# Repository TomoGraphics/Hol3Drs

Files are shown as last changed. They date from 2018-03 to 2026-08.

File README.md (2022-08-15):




# OpenSCAD models

This repository is a collection of sample holder for our [uCT scanners](http://bruker-microct.com/products/all_products.htm) (Bruker SykScan 1172, 1272 and 2214).

Models are generated/written in [OpenSCAD](http://www.openscad.org/).
The .scad-Files in this folder are the *originals*.
Those are then exported to [STL](https://en.wikipedia.org/wiki/STL_(file_format)) files (into the [STL](STL) folder) to be printed on our [Form 2](http://formlabs.com/products/3d-printers/form-2/) 3D printer.
This also makes it possible to nicely view the STL files, since [GitHub renders them in 3D](https://github.com/blog/1465-stl-file-viewing).

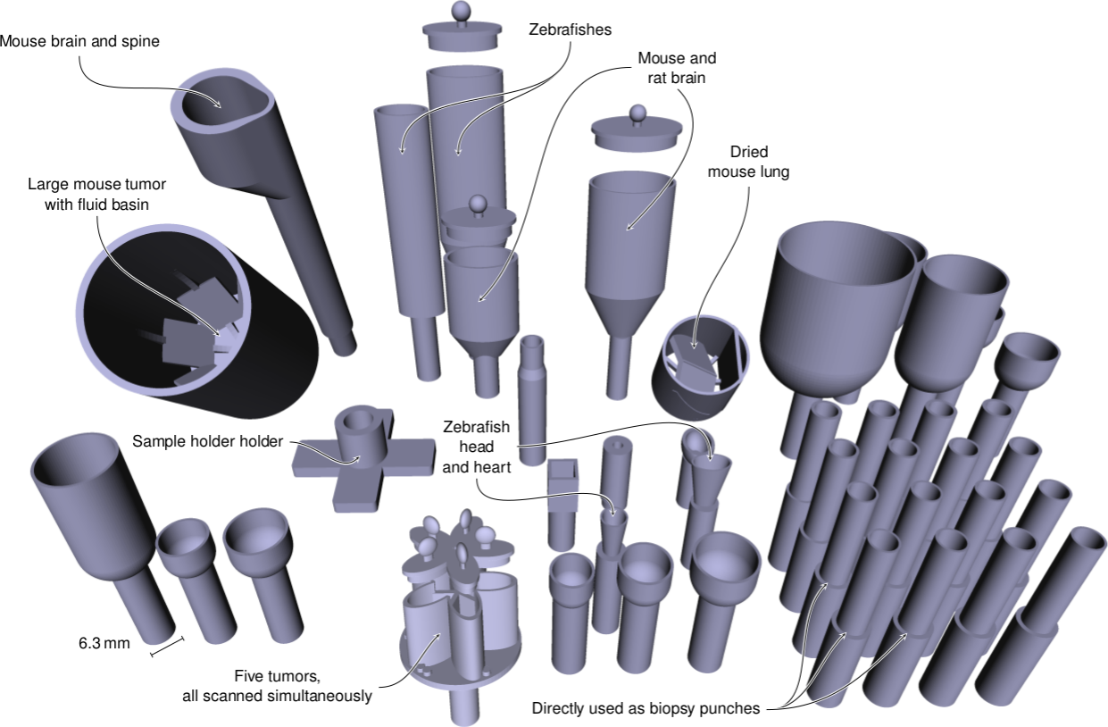
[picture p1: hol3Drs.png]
A sampler of our 3D printed sample holders


# [Contributions welcome](http://contributionswelcome.org/)

All contributions (no matter how small) are always welcome.
To see how you can help and where to start [see the Contributing file](CONTRIBUTING.md).

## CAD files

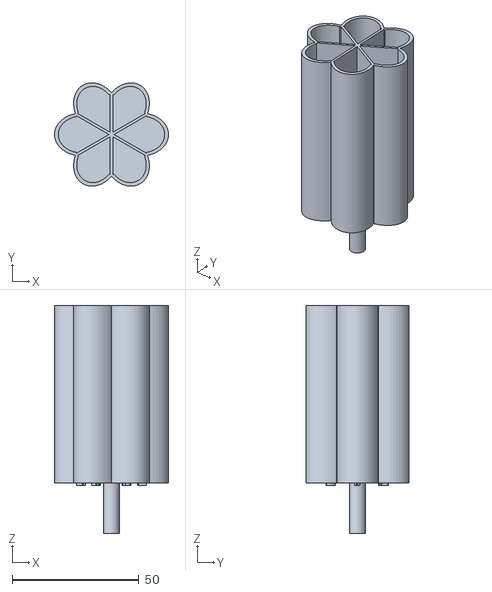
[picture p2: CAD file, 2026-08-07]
STL/Stickleback.Multiple.stl
45.0 x 40.8 x 90.0

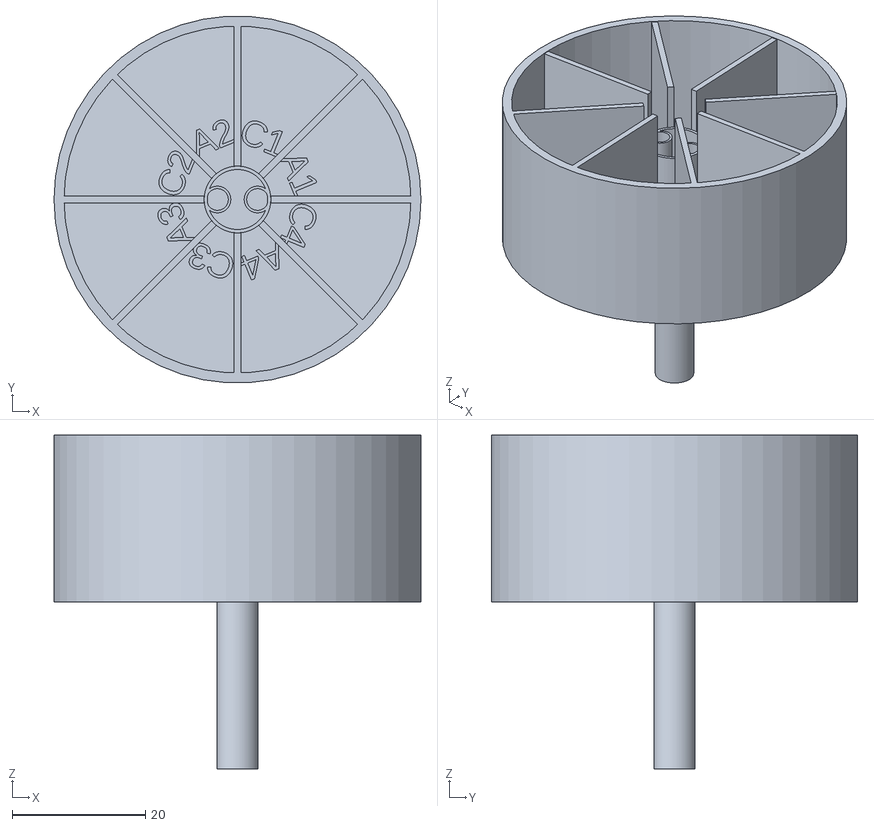
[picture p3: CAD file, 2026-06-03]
STL/BoneChunks.stl
55.0 x 54.9 x 50.0

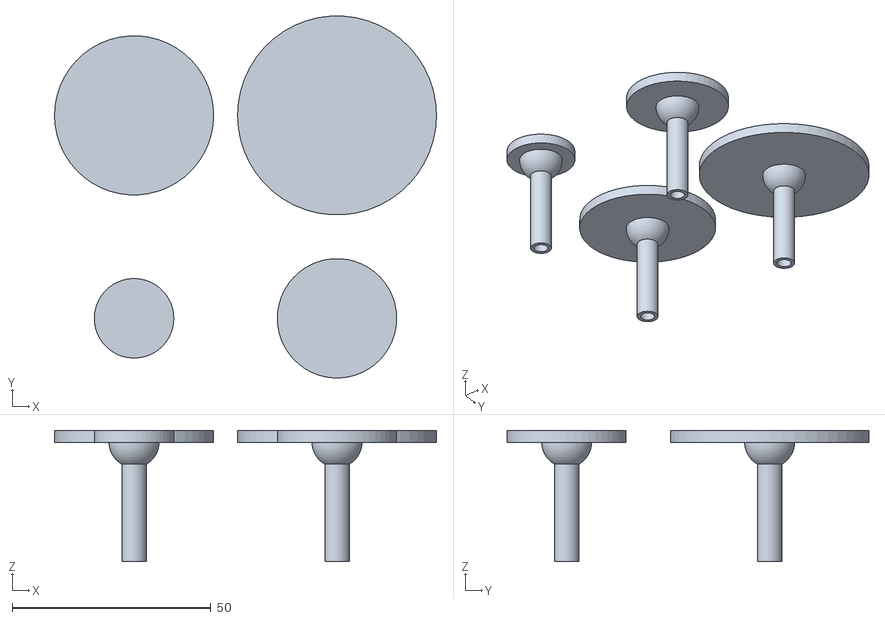
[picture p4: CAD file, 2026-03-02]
STL/SimplePlate.stl
96.0 x 90.9 x 33.0

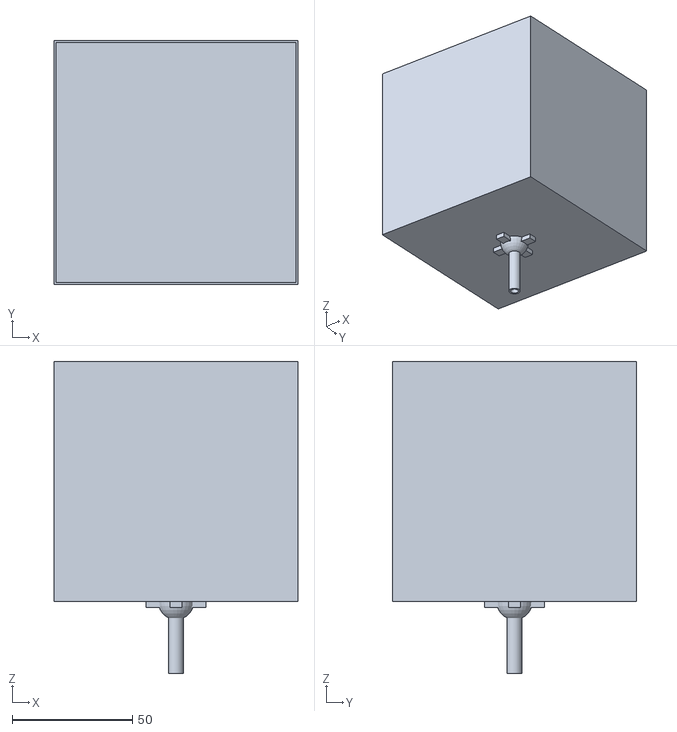
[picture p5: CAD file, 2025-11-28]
STL/Box.stl
101.5 x 101.5 x 130.0

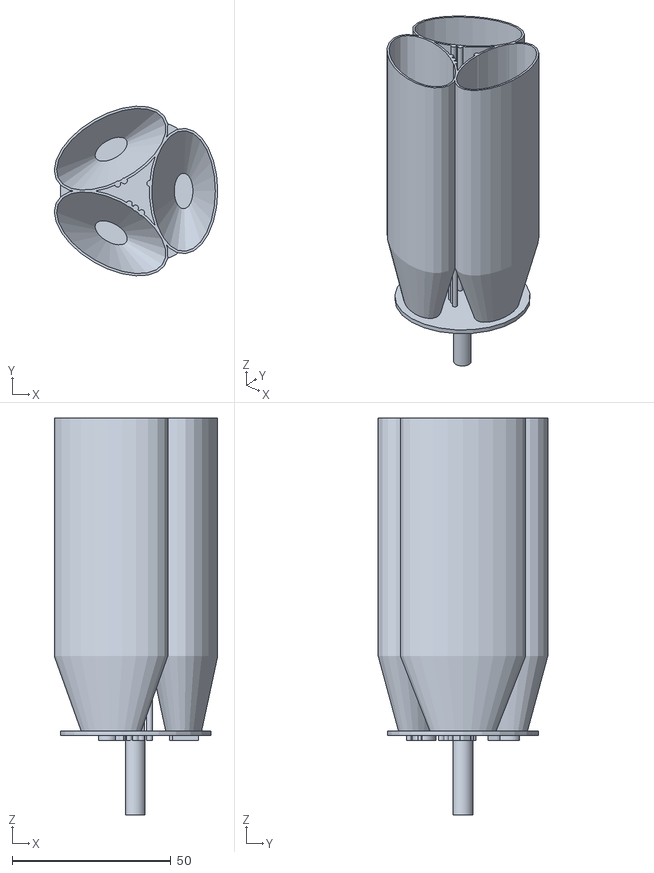
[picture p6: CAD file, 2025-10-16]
STL/EAWAG.Fish.Multiple.stl
51.5 x 53.4 x 125.0

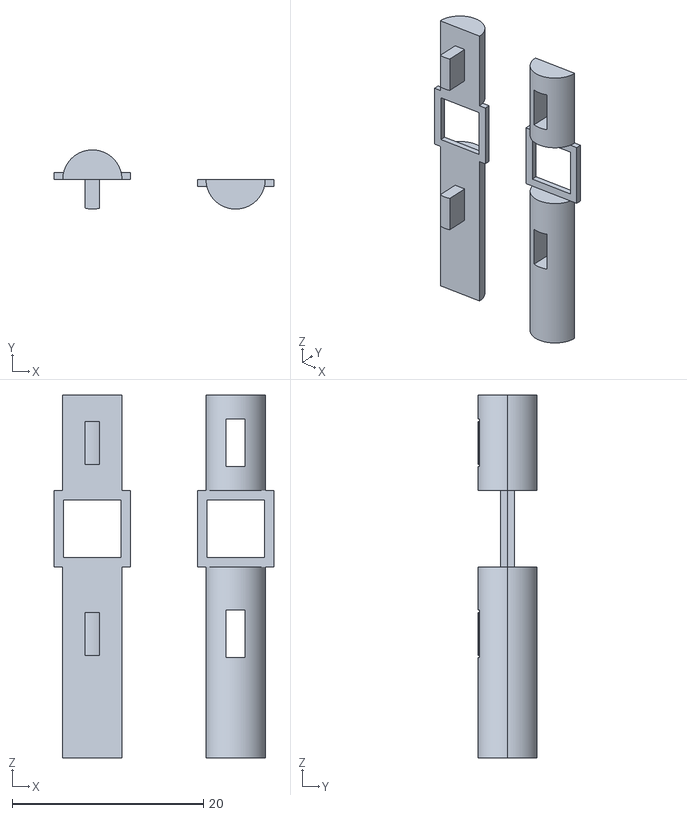
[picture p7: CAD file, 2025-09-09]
STL/FoamFrame.stl
23.0 x 6.20 x 38.0

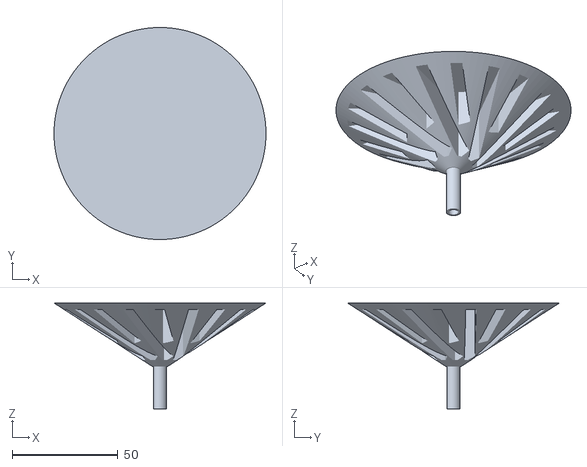
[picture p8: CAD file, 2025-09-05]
STL/BrukerHolderInPlastic.stl
100.0 x 100.0 x 50.0

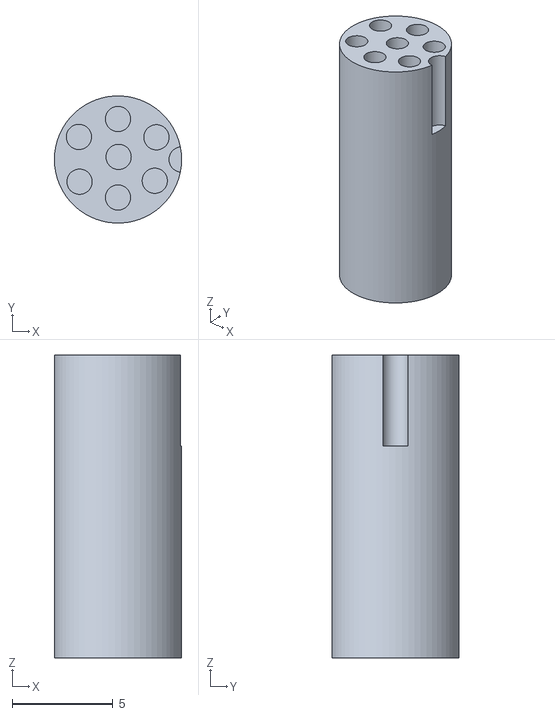
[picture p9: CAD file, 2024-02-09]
STL/DrillHolder.stl
6.30 x 6.29 x 15.0

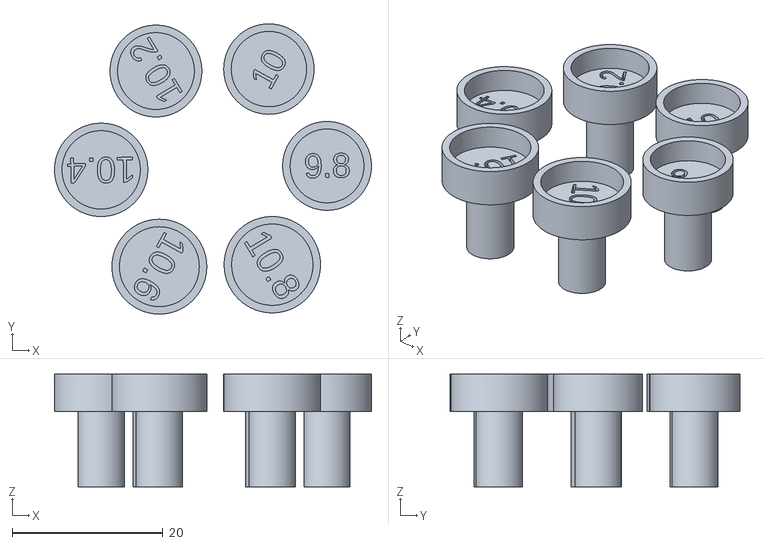
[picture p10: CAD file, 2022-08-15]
STL/Mouse.Lung.CriticallyPointDried.Kapton.stl
42.1 x 38.5 x 15.0

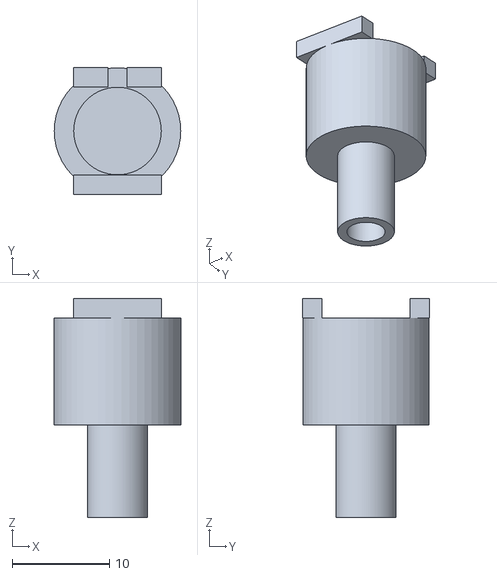
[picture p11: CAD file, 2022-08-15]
STL/Rabbit.Bone.Dome.stl
13.0 x 13.0 x 22.5

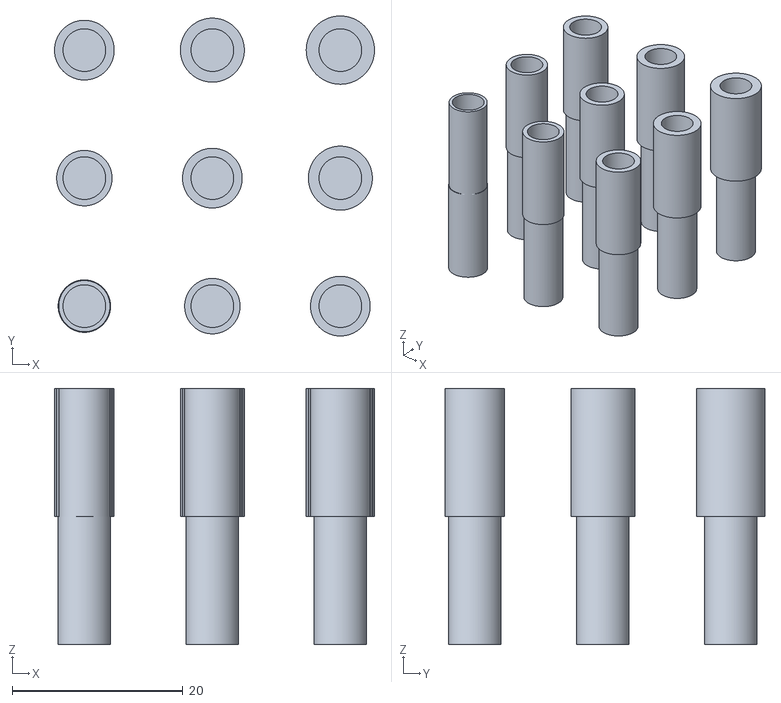
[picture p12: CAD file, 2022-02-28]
STL/Fossil.Shells.stl
37.5 x 37.5 x 30.0

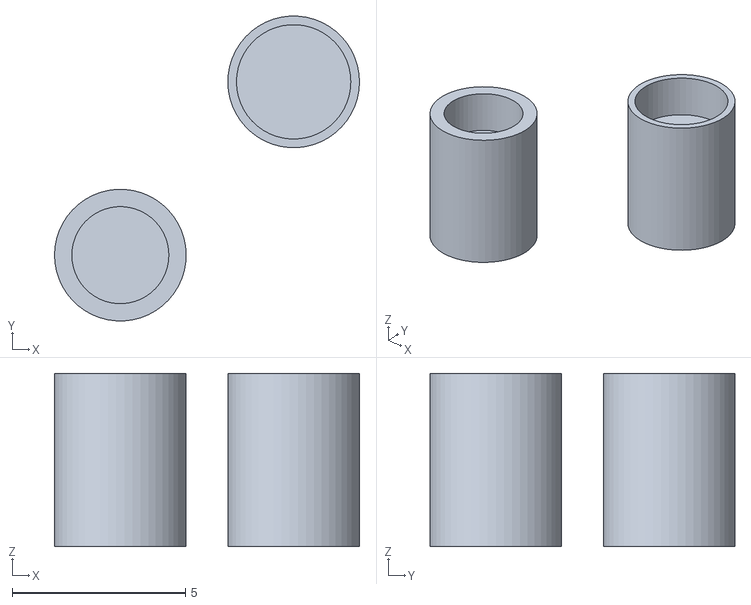
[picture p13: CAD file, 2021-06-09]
STL/Gastropod.Shell.Samplechanger.stl
8.80 x 8.79 x 5.00

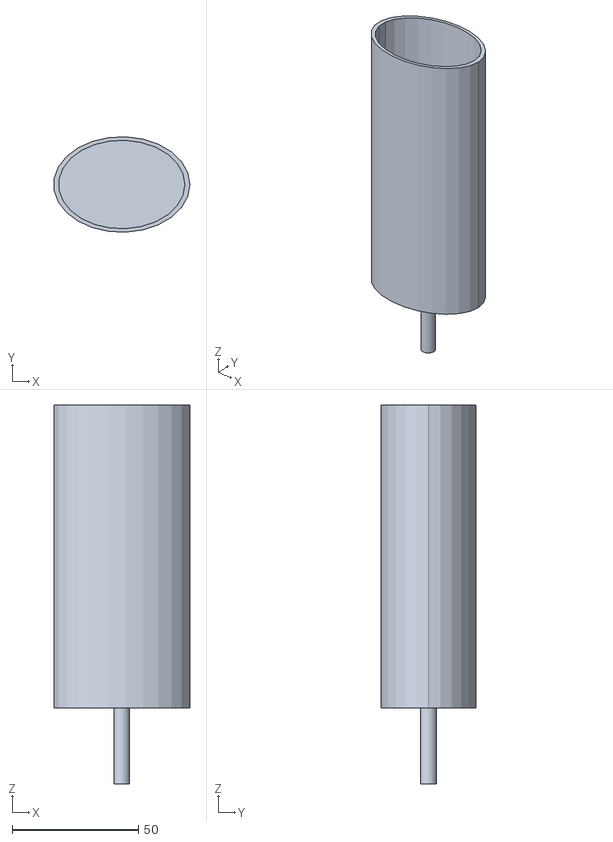
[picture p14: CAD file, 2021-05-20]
STL/EAWAG.Fish.stl
53.8 x 37.7 x 150.0

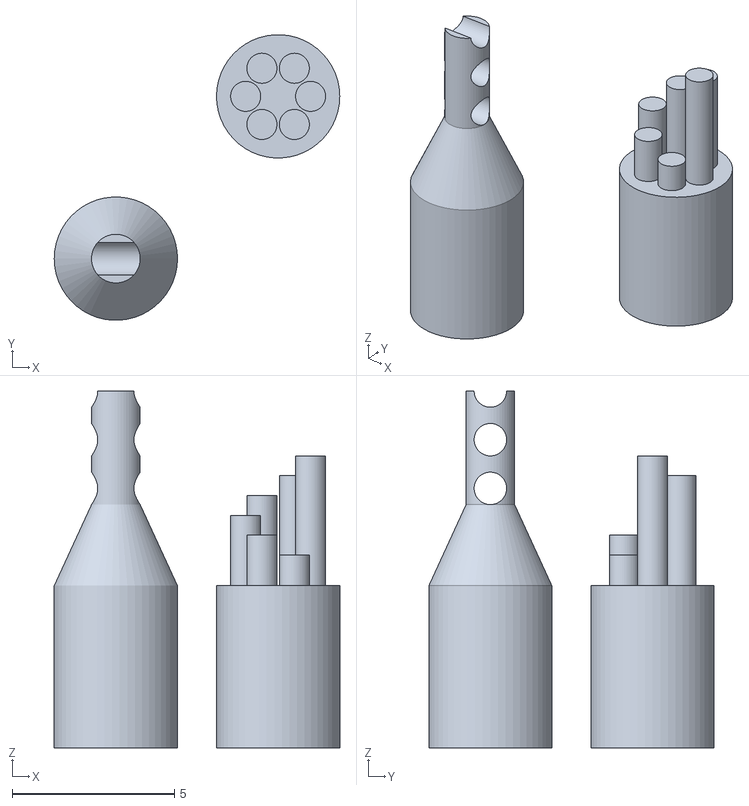
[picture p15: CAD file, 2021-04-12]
STL/Chondrules.stl
8.80 x 8.79 x 11.0

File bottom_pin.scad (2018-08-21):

// This is the bottom pin which is used to mount the sample holders into the machines.
// Since we use this for most of our models, it makes sense to have a small 'template' which we can just add the model where it's needed...
// To do so, add a line with "use<bottom_pin.scad>"
// And then just call "pin();" wherever you need the pin :)
$fn=100;
module pin(diameter=6.15, height=20, cap_depth=2)
{
    translate([0,0,-height]) difference(){
        cylinder(d=diameter,h=height);
        cylinder(d=diameter-2,h=height-cap_depth);
    }
}
pin();

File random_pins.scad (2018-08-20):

// Some random pins, with help from https://en.wikibooks.org/wiki/OpenSCAD_User_Manual/Mathematical_Functions

for(i=[0:100]){
    translate([rands(0,10,1)[0], rands(0,10,1)[0], 0]) cylinder(d=1, h=10);
    }

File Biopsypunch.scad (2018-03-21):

// Use the sample holder as biopsy punch

$fn=100;
bottom_pin_diameter = 6.2;

module sampleholder(cylinder_height,
                    cylinder_diameter,
                    wall_thickness=0.5,
                    pin_height=20,
                    ) {
    difference() { // Cut out cylinder with given diameter from cylinder with given diameter plus wall thickness
        union() { // Collect the bottom pin and the cylinder
            cylinder(d=6.25, h=pin_height); // Bottom pin
            translate([0,0,pin_height]) { // Move the sphere and cylinder up
                    cylinder(d=cylinder_diameter+wall_thickness,h=cylinder_height);
                    }
            }
            translate([0,0,pin_height]) {  // Move the drilling sphere and cylinder up
                #cylinder(d=cylinder_diameter, h=cylinder_height+1);
                    }
                }
            }

        
for (x = [0:10: 30]) {
    for (y = [0:10:20]) {
        translate([x,y,0]) sampleholder(20, 4, wall_thickness=0.75);
        }
    for (y = 20) {
        translate([x,y,0]) sampleholder(20, 4, wall_thickness=1);
        }        
    for (y = 30) {
        translate([x,y,0]) sampleholder(20, 4, wall_thickness=1.25);
        }                
    }

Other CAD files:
STL/Mouse.Lymphnode.Samplechanger.stl
STL/Rat.Heart.Samplechanger.stl
STL/tooth_holder3.stl
STL/Zebrafish.Heart.Samplechanger.stl
BoneChunks.scad
Box.scad
BrukerHolderInPlastic.scad
BucketSeparator.scad
Chondrules.scad
DrillHolder.scad
EAWAG.Fish.Multiple.scad
EAWAG.Fish.Samplechanger.scad
EAWAG.Fish.scad
FalconTubeHolder.scad
FoamFrame.scad
Fossil.Shells.scad
Gastropod.Shell.Samplechanger.scad
GenericSampleHolders.scad
Mouse.Brain.scad
Mouse.Eye.scad
Mouse.Heart.Wet.scad
Mouse.Lung.CriticallyPointDried.Kapton.scad
Mouse.Lung.CriticallyPointDried.RUL.scad
Mouse.Lung.CriticallyPointDried.scad
Mouse.Lung.Technovit.scad
Mouse.Lung.Wet.scad
Mouse.Lymphnode.Samplechanger.scad
Mouse.Melanoma.Multiple.scad
Mouse.Spine.scad
Mouse.Tumors.Big.scad
Mouse.Tumors.scad
Needle.scad
Rabbit.Bone.Dome.scad
Rabbit.Retina.scad
Rat.Brain.scad
Rat.Eye.scad
Rat.Heart.Samplechanger.scad
STL/Biopsypunch.stl
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

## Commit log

2018-02-23 Fork into work/play
    Work: https://github.com/TomoGraphics/Hol3Drs
    Play: https://github.com/habi/openscad
    [100Clip.stl, 350Clip.stl, Bike.scad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]
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2018-03-21 Rename models to more meaningful names
    Usually $ANIMAL.$ORGAN.$DETAIL.filename
    Or $THING.filename :)
    Also minor changes in the files and deletion of unnecessary files
    [Biopsypunch.scad, Biopsypunch.stl, GenericSampleHolders.scad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]
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2018-08-20 We learned about some random-ness in OpenSCAD
    This is a small snippet that will be used in the next model...
    [random_pins.scad, random_pins.stl]
2018-08-20 Holder for a (delicate) rabbit retina
    - we cannot just put it on a plate, or else we won't get it off again
    - we have to have a slight curve in the botton, to keep it as native as
    possible
    - we have to keep it wet at all times
    --> We use a squashed sphere to carve out a bed from some random open
    tube to try to fit all requirements.
    [Rabbit.Retina.scad]
2018-08-21 Rectangles instead of tubes as support
    Also a bit more understandable random coordinate generation.
    [Rabbit.Retina.scad]
2018-08-21 Slightly thinner pin with slightly thicker walls
    [bottom_pin.scad]
2018-11-12 More precise rendering in OpenSCAD
    [Rabbit.Retina.scad, Rabbit.Retina.stl]
2019-06-11 Holder for Technovit-embedded lungs
    The lungs are technovit-embedded and came to us on top of shaped plastic
    blocks.
    This holder makes it convenient to put the samples into the machine,
    since we're scanning a lot of them.
    [Mouse.Lung.Technovit.scad, Mouse.Lung.Technovit.stl]
2019-06-11 Several toothpick holders at once
    [Toothpick.scad, Toothpick.stl]
2019-06-11 Holder for wet mouse lungs
    The lungs contain a tumor, which we want to locate.
    The mouse lungs are wet because they go into histology after scanning.
    [Mouse.Lung.Wet.scad, Mouse.Lung.Wet.stl]
2019-06-11 New STL export, model unchanged
    [SampleHolderHolder.stl]
2019-08-21 Sometimes we just need to prop up a Falcon tube...
    [FalconTubeHolder.scad, FalconTubeHolder.stl]
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2020-02-14 Properly calculate the wall thickness
    [Mouse.Tumors.scad]
2020-02-14 We need to scan some fixed mouse hearts
    But also need to keep them wet, so let's make a little separator between
    the fluid and the hearts...
    [Mouse.Heart.Wet.scad, Mouse.Heart.Wet.stl]
2020-07-28 Holder for chondrules on the sample changer
    We want to use the [sample changer] of the 1272 to scan a lot of
    chondrules (from space).
    [sample changer]: https://www.youtube.com/watch?v=-TuW21TvarE
    [Chondrules.scad, Chondrules.stl]
2020-08-03 More chondrules, stacked
    To minimize scan time we fit more chondrules into the field of view of the scanner.
    [Chondrules.scad, Chondrules.stl]
2020-08-04 Better holes and other version, too
    Let's see which one is better suited for Yogita and Jan.
    [Chondrules.scad, Chondrules.stl]
2020-08-18 Add tooth holder
    https://cad.onshape.com/documents/bebb508e70519540512bbf85/w/42017ce07613bea707218121/e/0a840669cdf4311828d21d10
    [tooth_holder3.stl]
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2020-09-04 Add holder for zebrafish hearts for samplechanger
    [Zebrafish.Heart.Samplechanger.scad, Zebrafish.Heart.Samplechanger.stl]
2020-09-25 We have to scan a *lot* of larger fish
    [EAWAG.Fish.Samplechanger.scad, EAWAG.Fish.Samplechanger.stl]
2020-09-25 Too big for the sample changer, e.g. print with the pin, too
    [EAWAG.Fish.Samplechanger.scad]
2020-09-25 A little bit smaller so we can actually fit it in the sanner
    [EAWAG.Fish.Samplechanger.scad, EAWAG.Fish.Samplechanger.stl]
2020-11-02 Scan the hearts of Ludovic with the Samplechanger
    Based on the 'generic sampleholder'
    [Rat.Heart.Samplechanger.scad, Rat.Heart.Samplechanger.stl]
2020-11-30 Sample holder for mouse lymph nodes
    'Forked' from the zebrafish heart holders
    TODO: Adapt to larger samplechanger holder, the 4mm one is too small
    [Mouse.Lymphnode.Samplechanger.scad, Mouse.Lymphnode.Samplechanger.stl]
2020-12-01 Let's use the larger sample changer pin
    [Mouse.Lymphnode.Samplechanger.scad, Mouse.Lymphnode.Samplechanger.stl]
2020-12-21 Skeleton of well-plate stamp for Alex
    [WellPlateStamp.scad]
2021-01-22 Some bigger fish to fry, eh scan
    [EAWAG.Fish.Samplechanger.scad, EAWAG.Fish.Samplechanger.stl]
2021-01-28 Fix thickness of wall, print some more sizes
    [EAWAG.Fish.Samplechanger.scad, EAWAG.Fish.Samplechanger.stl]
2021-04-12 Rename and update fish holder
    We need to scan more smaller fishes
    [EAWAG.Fish.Samplechanger.stl, EAWAG.Fish.scad, EAWAG.Fish.stl]
2021-04-12 Update Yogitas chondrule holders
    [Chondrules.scad, Chondrules.stl]
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2021-06-09 Small 'holder' to scan a small gastropod shell
    [Gastropod.Shell.Samplechanger.scad, Gastropod.Shell.Samplechanger.stl]
2022-02-28 Add small holder for a scan of some small shells
    [Fossil.Shells.scad, Fossil.Shells.stl]
2022-04-04 Add holder for CPD lungs in Kapton tubes
    [Mouse.Lung.CriticallyPointDried.Kapton.scad, Mouse.Lung.CriticallyPointDried.Kapton.stl]
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2024-02-09 Update drill holder for scanning 7 at a time
    [DrillHolder.scad, DrillHolder.stl]
2024-12-30 fix use of bottom_pin_diameter in Mouse.Brain.scad
    [Mouse.Brain.scad]
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2025-06-04 Add marker that is visible along the whole axis
    [EAWAG.Fish.Multiple.scad, EAWAG.Fish.Multiple.stl]
2025-06-27 Add small "exploded" holder to prop up thin things
    [FoamFrame.scad, FoamFrame.stl]
2025-09-05 We need to hold something *not* on metal
    [BrukerHolderInPlastic.scad, BrukerHolderInPlastic.stl]
2025-09-09 A tad more slack is needed for assembly
    [FoamFrame.scad, FoamFrame.stl]
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2026-03-30 Add model for dividing walls in a bucket
    With parametrized amount of walls and some randomly seeded holes to save
    some material
    [BucketSeparator.scad]
2026-06-03 Add compartementalized holder for chunks
    Quasi an iteration on the EAWAG multi-fish holder.
    Labeling in the loop is assisted by Google Gemini.
    [BoneChunks.scad, BoneChunks.stl]
2026-08-07 Update "label" placement
    Outside of the holder is more convenient
    [Stickleback.Multiple.stl]
